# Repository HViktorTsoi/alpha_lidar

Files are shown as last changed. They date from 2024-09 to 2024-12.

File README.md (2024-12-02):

This is the official implementation of the paper **𝛼LiDAR: An Adaptive High-Resolution Panoramic LiDAR System (MobiCom 2024)**. 

# 𝛼LiDAR: An Adaptive High-Resolution Panoramic LiDAR System

The performance of current LiDAR sensors is hindered by limited field of view (FOV), low resolution, and lack of flexible focusing capability. We introduce 𝛼LiDAR, an innovative LiDAR system that employs controllable actuation to provide a panoramic FOV, high resolution, and adaptable scanning focus. See our demos below $\color{red}{\textbf{(3.7k+ views)}}$:

## Demo Video (YouTube)
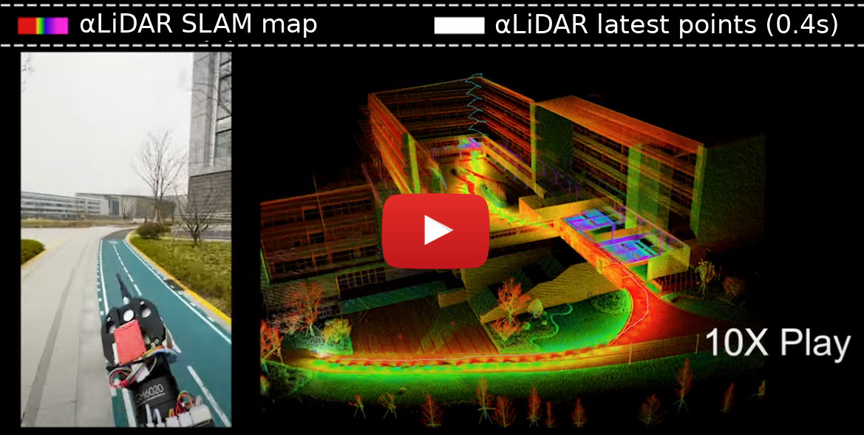
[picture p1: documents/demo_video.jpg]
alpha_lidar_demo_video (https://www.youtube.com/watch?v=x4zc_I_xTaw)


## System Overview 

The core concept of 𝛼LiDAR is to expand the operational freedom of a LiDAR sensor through the incorporation of a controllable, active rotational mechanism. This modification allows the sensor to scan previously inaccessible blind spots and focus on specific areas of interest in an adaptive manner. A major challenge with 𝛼LiDAR is that rapid rotations result in highly distorted point clouds. Our solution focuses on accurately estimating the LiDAR sensor’s pose during rapid rotations to effectively correct and reconstruct the point cloud.

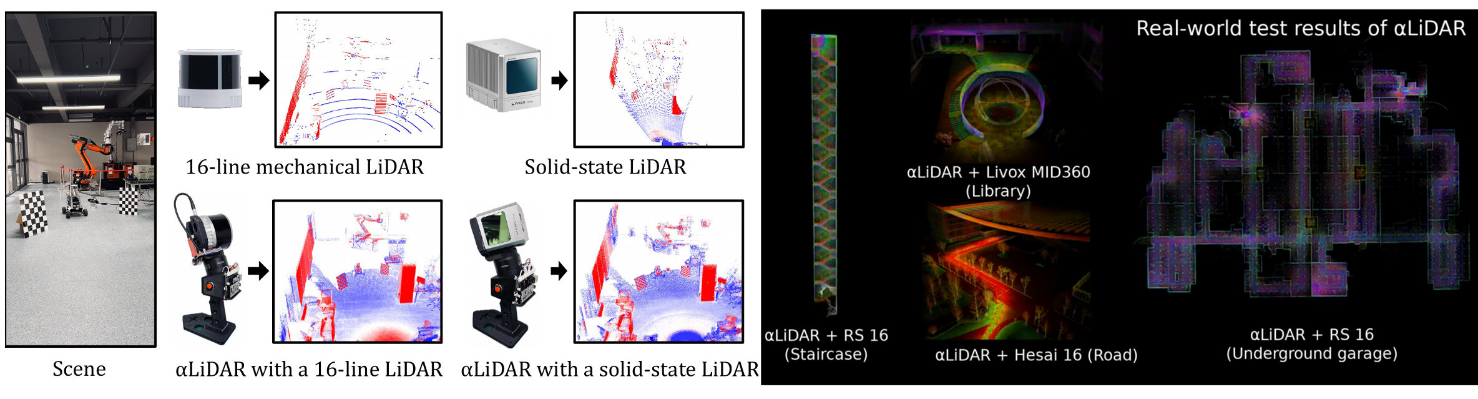
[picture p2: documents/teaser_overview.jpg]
Teaser)


# Table of Contents
This repository contains the hardware specifications, software, and datasets for reproducing and evaluating 𝛼LiDAR:

[//]: # (- [Demo video &#40;YouTube&#41;]&#40;#demo-video-youtube&#41;)
[//]: # (- [System Overview]&#40;#system-overview&#41;)
- [How to Use This Repo](#how-to-use-this-repo)
- [:gear: I. Hardware Guideline](#gear-i-hardware-guideline)
  - [1. Bill of Materials](#1-bill-of-materials)
  - [2. Build the Mechanical Components](#2-build-the-mechanical-components)
  - [3. Setup the Electronic Components](#3-setup-the-electronic-components)
- [:minidisc: II. Datasets](#minidisc-ii-prepare-code-and-datasets)
- [:scroll: III. Software Guideline](#scroll-iii-software-guideline)
  - [Run with Docker (Recommended)](#run-with-docker-recommended)
  - [Build Source from Scratch](#build-source-from-scratch)
- [License](#license)

# How to Use This Repo:

We offer two approaches for reproducing 𝛼LiDAR:

### Approach 1: Build the hardware from scratch, and then test 𝛼LiDAR's algorithm.

We provide a detailed hardware guideline, including design files and production parameters for mechanical and electronic parts, along with a step-by-step replication tutorial. 
Once the hardware is set up, users can collect datasets and test 𝛼LiDAR in real-time and on-site.
To begin, please refer to the [⚙️ I. Hardware guideline](#gear-i-hardware-guideline) and follow the instructions in the specified order.

### Approach 2: Directly test 𝛼LiDAR's core algorithm with pre-collected datasets.

We also provide pre-collected datasets with 𝛼LiDAR's. These datasets allow the users to directly test the performance of 𝛼LiDAR's core software components. 
For this approach, please directly refer to  [:minidisc: II. Prepare code and datasets](#minidisc-ii-prepare-code-and-datasets) and [# :scroll: III. Software guideline](#scroll-iii-software-guideline). 

# :gear: I. Hardware Guideline

𝛼LiDAR enhances its sensing ability by incorporating an activate rotation mechanism in the FoV-limited directions in the physical layer, therefore, implementing the complete hardware system is important. 
In this section, we will demonstrate the assembly of the hardware in detail, including the setup of sensors, mechanical structures and electronic components. 
We provide comprehensive Bill of Materials, 3D printing instructions, PCB designing and manufacturing details and firmware setup guides to ensure easy replication of 𝛼LiDAR. 
Following this guide, users can reproduce the full 𝛼LiDAR hardware system, as shown bellow, for data collection and performance validation.

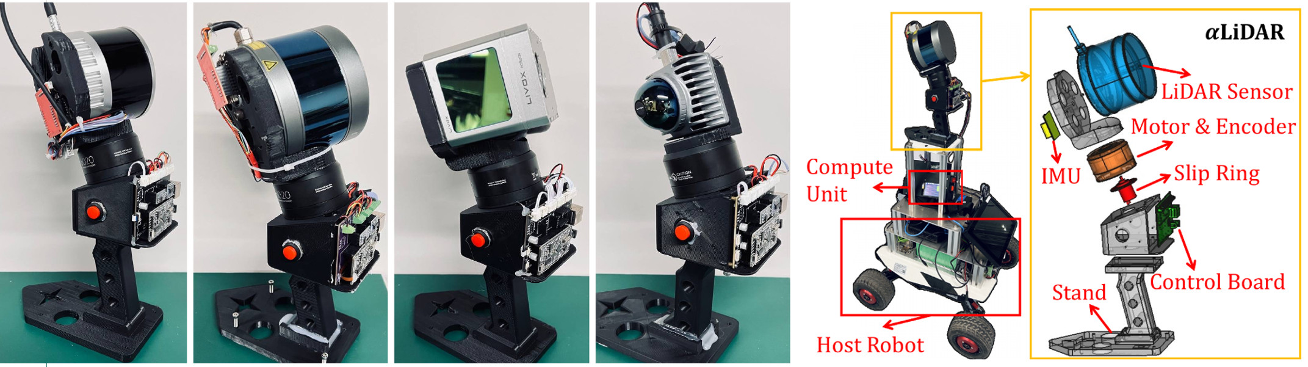
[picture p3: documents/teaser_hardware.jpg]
Teaser)


## 1. Bill of Materials

This section provides all materials required to replicate 𝛼LiDAR, including sensors, mechanical parts, electronic components, etc. 
Please prepare these materials before building 𝛼LiDAR.

Starting with sensors and actuators, 𝛼LiDAR requires a LiDAR with PPS/GPRMC time synchronization support (which is commonly built into most LiDARs).
𝛼LiDAR also requires an IMU and an encoder for state estimation, and a gimbal motor as the actuator for the active motion. The encoder is usually integrated into the gimbal motor such as DJI GM6020.
Specific models of these components are listed in the table below:

<details>
<summary>Click here to show the material list</summary>

| Component | Quantity | Detail | Link |
|---|---|---|---|
| Hesai Pandar XT-16 (*) | 1 | LiDAR with PPS+GPRMC sync support | [link](https://www.hesaitech.com/product_downloads/xt32-16/) |
| Yesense YIS100 | 1 | IMU | [link](https://www.yesense.com/YIS100) |
| Robomaster GM6020 | 1 | Motor / Encoder | [link](https://www.robomaster.com/en-US) |
> (*) Or other LiDAR sensors, e.g., [Robosense RS16](https://www.robosense.ai/en) / [Livox MID360](https://www.livoxtech.com/) / [Livox Horizon](https://www.livoxtech.com/).

</details>

Next, here are the mechanical and electronic parts required. Most of them can be purchased online with low cost. The purchase links are also provided if available.

<details>
<summary>Click here to show the material list</summary>

| Component | Quantity | Detail | Link |
|---|---|---|---|
| **Mechanical Parts** | | | |
| LanBo PLA+  filement | 1 | 3D printing filement | [link](http://e.tb.cn/h.gsp9zhNGv3aDk1e?tk=9Jja38xDsqf) |
| Central mounting structure | 1 | 3D printed part | [.step](hardware/Mechanical/center_mounting_structure_hesai.step)  |
| Motor mounting base | 1 | 3D printed part | [.step](hardware/Mechanical/motor_mounting_base.step) |
| Stand | 1 | 3D printed part | [.step](hardware/Mechanical/stand.step) |
| Hex socket cap screws | 18 | 7 x M3 x 10mm, 7 x M4 x 10mm, 4 x M4 x 25mm | - |
| W1/4-20 screws | 1 | - | - |
| **Electronic Parts** | | | |
| Control board | 1 | PCB | [link](hardware/PCB/EasyEDA_PCB_control_board.json) |
| Host machine interface | 1 | PCB | [link](hardware/PCB/EasyEDA_PCB_host_machine_interface.json) |
| STM32F103C8 Dev Board | 1 | MCU | [link](http://e.tb.cn/h.grrLx6RYA14IKhd?tk=78g03iXNOQm) |
| SP3232 Module | 1 | RS232-TTL converter | [link](http://e.tb.cn/h.gJosLscFDzw8Mb8?tk=u5v037C8lvo) |
| TJA1050 CAN Module | 1 | CAN controller | [link](http://e.tb.cn/h.gJRE7eLncdnfH2f?tk=bT1N37CR3JV) |
| CH340C SOP16 | 1 | USB-Serial converter | [link](http://e.tb.cn/h.gJLbUM7WQJP9YyL?tk=Q6bh37CsSeL) |
| SL2.1A SOP16 | 1 | USB hub controller | [link](http://e.tb.cn/h.gJ8WnEJFgmtsBG9?tk=nUKr37Cryhm) |
| 0805 chip beads | 1 | EMI protection | [link](http://e.tb.cn/h.gHOAsfEj4iIVgE7?tk=P8kt38CdGI0) |
| RJ45 Socket | 3 | Control board x1, interface board x2 | [link](http://e.tb.cn/h.gJRwBsI2jhjfMgq?tk=Blwl37Cjqox) |
| XH2.54 Socket | 5 | 8pin x1, 4pin x2, 2pin x2 | [link](http://e.tb.cn/h.gJRx9rqzKRJdwGG?tk=2ZND37CQ6tV) |
| Gigabit Ethernet cable | 1 | 8-line, for data transmission | - |

</details>

## 2. Build the Mechanical Components

𝛼LiDAR's mechanical components including the structural parts for mounting the LiDAR, IMU, Motor, and the control board. 
Our design is optimized for 3D printing to facilitate rapid prototyping and reproducing. 

### 2.1 Prepare the CAD Models:
First, download the following CAD models of the mechanical components. 
The user can preview the assembly diagram and the part files with [FreeCAD](https://www.freecad.org/) software and [A2plus plugin](https://wiki.freecad.org/A2plus_Workbench).

<details>
<summary>Click here to show the CAD files: </summary>

- Assembly diagram: 

[hardware/Mechanical/assembly.FCStd](hardware/Mechanical/assembly.FCStd)

- LiDAR-IMU-Motor central mounting structure (for Hesai Pandar XT16)

[hardware/Mechanical/center_mounting_structure_hesai.step](hardware/Mechanical/center_mounting_structure_hesai.step)

- LiDAR-IMU-Motor central mounting structure (for Robosense RS16)

[hardware/Mechanical/center_mounting_structure_rs16.step](hardware/Mechanical/center_mounting_structure_rs16.step)

- Motor mounting base

[hardware/Mechanical/motor_mounting_base.step](hardware/Mechanical/motor_mounting_base.step)

- Stand

[hardware/Mechanical/stand.step](hardware/Mechanical/stand.step)

</details>

### 2.2 Build the Components with a 3D Printer

The users can then import the above STEP files into a 3D printing slicing software, set the printing parameters to generate the `.gcode` files, and then use a 3D printer to build the parts.
For reference, we use a **SnapMaker A350 3D printer**, and use **Ultimaker Cura 4.9.1** for model slicing.

<details>
<summary>Click here to show the key parameters for 3D printing: </summary>

- **Printing material:** Lanbo PLA+
- **Temperature:** 200C
- **Heat bed:** 60C
- **Cooling fan:** 100%
- **Nozzle diameter:** 0.4mm
- **Layer height:** 0.24mm
- **Wall line count:** 4
- **Top-bottom layers:** 4
- **Infill:** 60% Gyroid
- **Support:** On
- **Adhesion:** On 
- **Build plate adhesion type:** Brim

</details>

To ensure that the printed parts have sufficient layer strength during rapid rotations, we require specific placement for the models in the slicing software.
The orientation of the sliced models should be positioned like this:

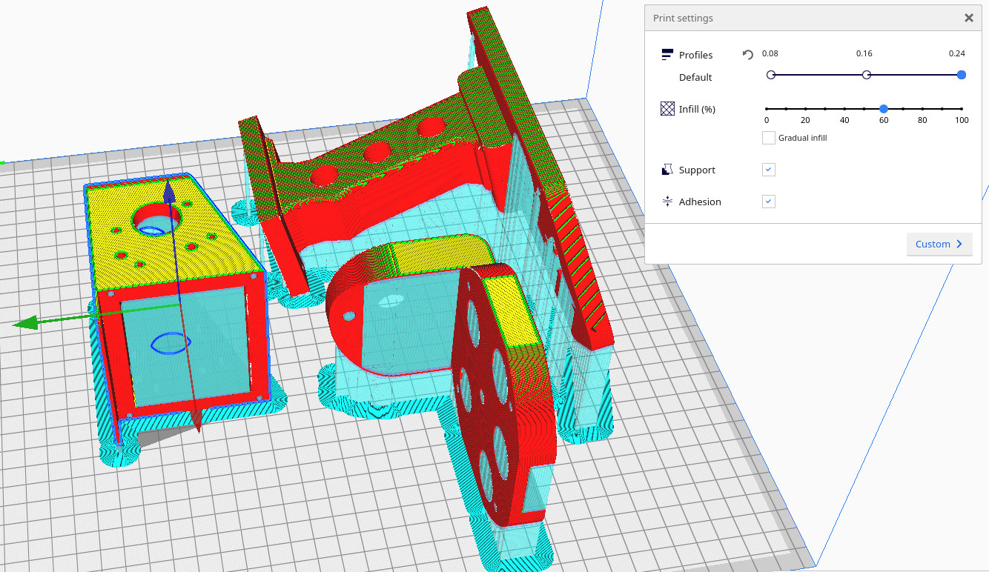
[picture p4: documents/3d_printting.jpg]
3D Printing Preview


## 3. Setup the Electronic Components

𝛼LiDAR's electronic components mainly consists of two PCBs:  the **control board** and the **host machine interface**.

The **control board** is mounted together with the Motor, LiDAR, IMU sensor, aggregating all sensor data onto a single RJ45 physical interface, and transmitting the data via a 8-line gigabit Ethernet cable; 

the **host machine interface** splits the 8-line gigabit Ethernet cable into a 4-line 100Mbps Ethernet and a USB 2.0 interface, connecting to the host computer.

### 3.1 Preview the PCB Designing Files

<details>
<summary>Click here to show the PCB design files: </summary>

- Control board PCB design file:

[hardware/PCB/EasyEDA_PCB_control_board.json](hardware/PCB/EasyEDA_PCB_control_board.json)

- Host machine interface PCB design file:

[hardware/PCB/EasyEDA_PCB_host_machine_interface.json](hardware/PCB/EasyEDA_PCB_host_machine_interface.json)

</details>

The PCB design files can be imported and previewed in [EasyEDA](https://easyeda.com/editor). After successful importation, the appearance of the PCB should look as shown in the following images:

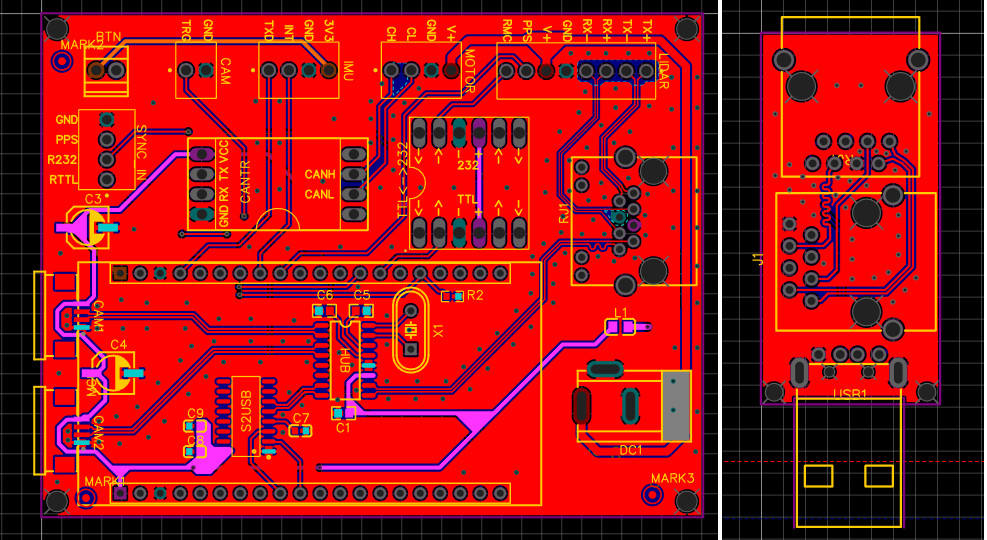
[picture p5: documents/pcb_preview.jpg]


### 3.2 Manufacture the PCBs

The PCBs can be manufactured using [JLCPCB's PCB Prototype service](https://docs.lceda.cn/en/PCB/Order-PCB/), which has been integrated within EasyEDA.

<details>
<summary>Click here to show the key parameters for PCB fabrication: </summary>

- **Base Material:** FR-4
- **Layers:** 2
- **Product Type:** Industrial/Consumer electronics
- **PCB Thickness:** 1.6
- **Surface Finish:** HASL(with lead)
- **Outer Copper Weight:** 1oz
- **Min via hole size/diameter:** 0.3mm
- **Board Outline Tolerance:** +-0.2mm

</details>

To assemble the MCU and other electronic components onto the PCB, we can use [JLCPCB's SMT service](https://jlcpcb.com/smt-assembly), or solder by hand. The fully assembled PCB is shown in the following images:

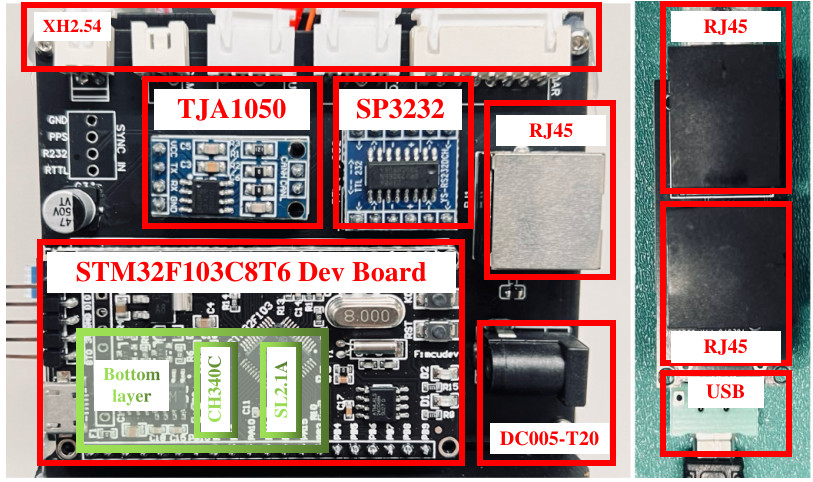
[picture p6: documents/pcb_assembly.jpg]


### 3.3 Uploading the Firmware

The firmware needs to be programmed into the STM32 MCU on the control board. It includes all the functionalities necessary for the board to operate properly, including data acquisition from multiple sensors, time synchronization,  protocol conversion, etc. 

The hex file of the firmware:
[hardware/Firmware/stm32f103c8t6.hex](hardware/Firmware/stm32f103c8t6.hex)

To program the firmware onto the MCU, we need an [ST-LINK V2](https://www.st.com/en/development-tools/st-link-v2.html) programmer. Please refer to the programming process outlined in the[STM32CubeProgrammer user manual](https://www.st.com/resource/en/user_manual/um2237-stm32cubeprogrammer-software-description-stmicroelectronics.pdf).

### 3.4 Wire Everything Together

After preparing all the required sensors, actuators, and the assembled PCB, please connect the components according to the wiring diagram below. 
The diagram includes the PIN definitions for each sensor's XH2.54 interface, arranged in the same order as they appear on the actual PCB. 
The entire PCB (and the sensors) can be powered through a DC 24V input.

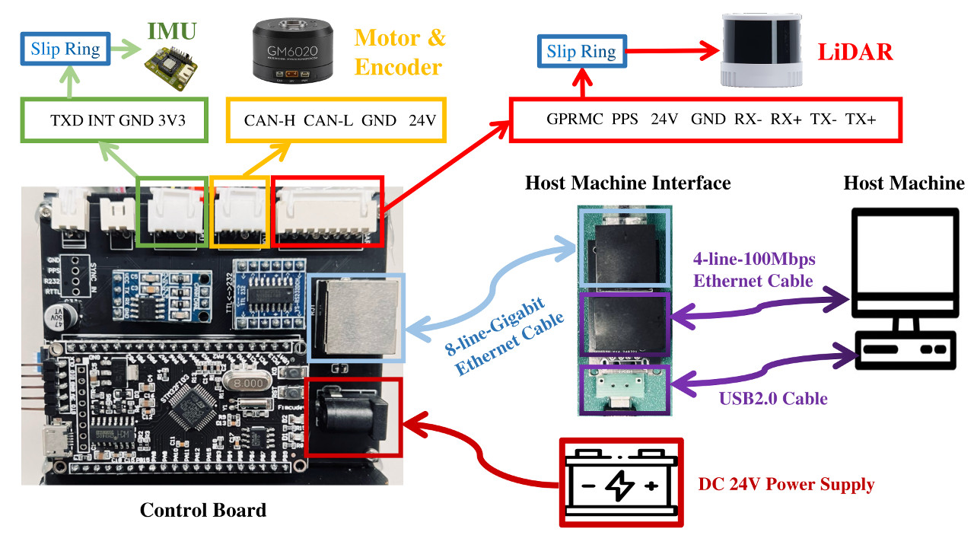
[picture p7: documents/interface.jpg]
Wire


# :minidisc: II. Prepare Code and Datasets

We also provide multiple pre-collected datasets to test 𝛼LiDAR's performance if the hardware is not available. The dataset can be downloaded at [Mega Drive](https://mega.nz/folder/fEpwARjD#AVRIQ-gzrFtTJn6fuwmXng) or [Baidu Pan (Code: u0tr)](https://pan.baidu.com/s/1nzBAgfkNCF8X1rAMBUw8Rg).

**Dataset description:**

| Test dataset | Description | Scene image and map |
|---|---|:---:|
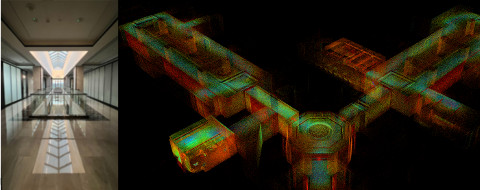
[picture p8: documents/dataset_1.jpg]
data
| alpha_lidar_large_indoor.bag | Indoor environment with narrow corridors and reflective floors |  |
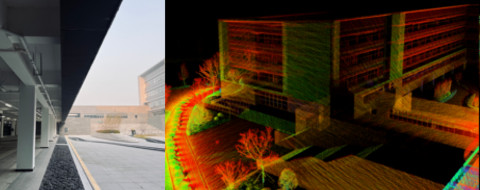
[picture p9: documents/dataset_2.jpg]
data
| alpha_lidar_various_scene.bag | Hybrid indoor and outdoor environment |  |
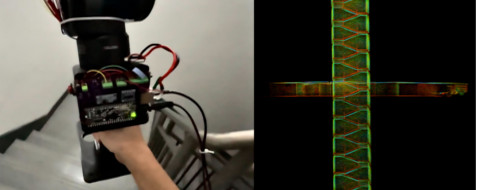
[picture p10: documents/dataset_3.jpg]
data
| alpha_lidar_15floors_staircase.bag | 15-Floor narrow stairwell |  |

To use our code and datasets, first, clone this repository:
```shell
git clone https://github.com/HViktorTsoi/alpha_lidar.git
```

Download the datasets and save to this path: 
```shell
${path_to_alpha_lidar}/datasets
```
`${path_to_alpha_lidar}` is the path to the source code just been cloned. 

After downloading, the `alpha_lidar/datasets` directory should look like this:

```shell
|-- datasets
|---- alpha_lidar_15floors_staircase.bag
|---- alpha_lidar_large_indoor.bag
|---- alpha_lidar_large_indoor.fusion.gt
|---- alpha_lidar_various_scene.bag
|---- alpha_lidar_various_scene.f9p.gt
```
The `*.bag` files store the raw data (LiDAR point cloud, IMU and Encode messages), while the corresponding `*.gt` files store the ground truth data.

# :scroll: III. Software Guideline

> A step-by-step video tutorial for this section is available at https://www.youtube.com/watch?v=jFgedPY6zIM

In this section, we demonstrate how to run and evaluate 𝛼LiDAR's core software module, which addresses 𝛼LiDAR' main challenges: accurately estimating the LiDAR's poses and recovering undistorted LiDAR measurements under the rapid motion of both the LiDAR and the carrier.

We offer two methods for running the 𝛼LiDAR code: 
[running with docker (we recommend)](#run-with-docker-recommended) and [building the source code from scratch](#build-source-from-scratch).

## Run with Docker (Recommended)

### Prerequisites

- Ubuntu 18.04 or later
- NVIDIA GPU Driver
- [docker](https://docs.docker.com/get-docker/)
- [nvidia-docker2](https://docs.nvidia.com/datacenter/cloud-native/container-toolkit/install-guide.html)
- [docker-compose](https://docs.docker.com/compose/install/linux/#install-using-the-repository)

### 1. Setup Docker Environment
First, pull our preconfigured environment from docker hub
```shell
docker pull hviktortsoi/ubuntu2004_cuda_ros:latest
```
Then, enter the `docker` directory in the source code

```shell
cd ${path_to_alpha_lidar}/software/docker
```
`${path_to_alpha_lidar}` is the path where the source code just been cloned. 

Before start the container, configure `xhost` on the host machine by:
```shell
sudo xhost +si:localuser:root
```

Then launch and enter the docker container:
```shell
sudo docker-compose run alpha-lidar bash
```

### 2. Run and Evaluate

The following steps are all executed in the bash terminal inside the docker container. 
#### 2.1 Run αLiDAR

Taking the `alpha_lidar_various_scene.bag` dataset as an example, to launch αLiDAR's `state estimation` module, execute:

```shell
roslaunch state_estimation mapping_robosense.launch bag_path:=/datasets/alpha_lidar_large_indoor.bag
```
After launching, press `space` key in the **bash terminal** to begin data playback.

If everything is working smoothly, two RVIZ GUI windows will show up:

The first RVIZ window shows the visualization of αLiDAR's **point cloud maps** and **estimated poses**. 
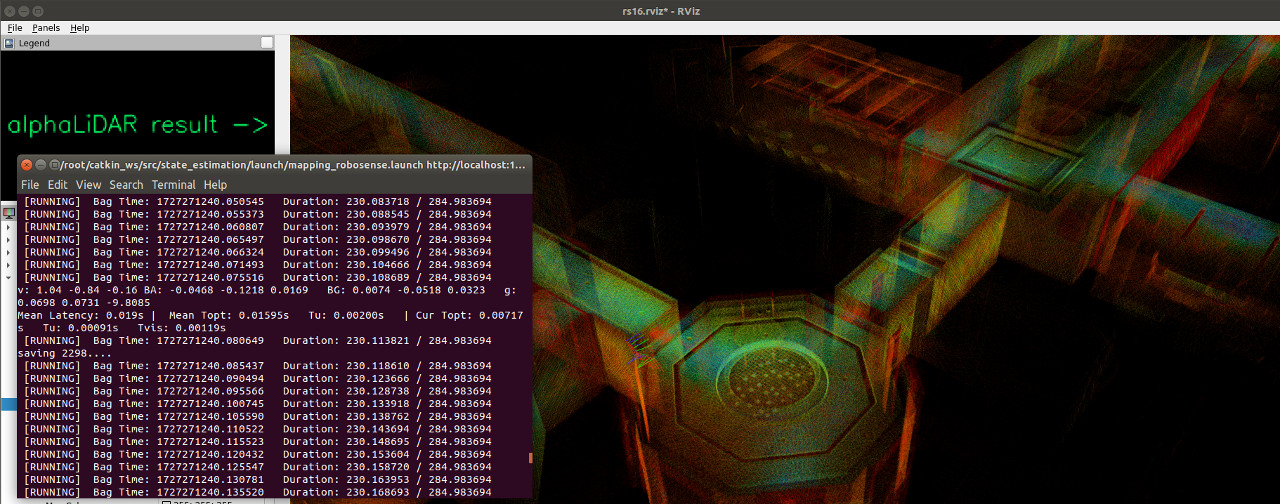
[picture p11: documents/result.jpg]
result


The smaller second window shows the comparison result, which is naïvely stacking the raw point clouds without αLiDAR's pipeline.

[//]: # (![result]&#40;documents/result3.jpg&#41;)
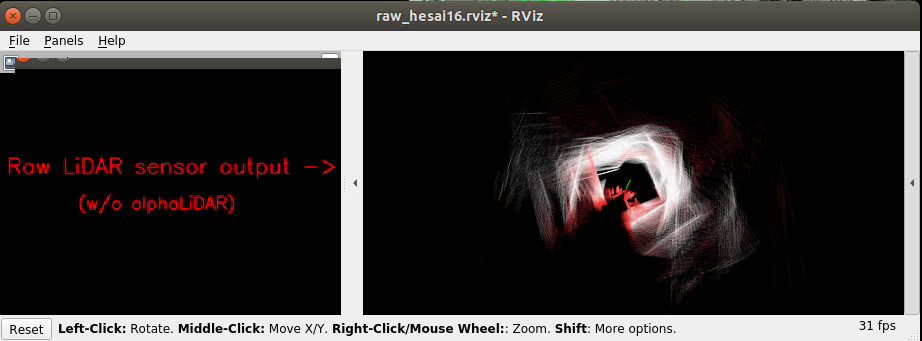
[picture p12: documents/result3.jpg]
result


Additionally, the bash terminal will display the debug information like data playback time, real-time latency, etc.

Users can use the mouse **Left-click**, **Middle-scroll** and **Middle-click** to move the viewpoint in the RVIZ GUI to observe a more comprehensive point cloud map. 

During visualization, if the users lost the point cloud view, press `z` key in the RVIZ GUI to reset the viewpoint;
If the point clouds are not clear, try increasing the `Size (m)` parameter (e.g., to 0.05) in the left configuration panel to make the point cloud more visible.

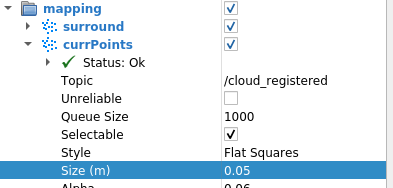
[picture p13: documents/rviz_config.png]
config


#### 2.2 Evaluate αLiDAR's Performance
After completing data playback, press CTRL+C in the  **bash terminal** to exit `state estimation`.

To evaluate αLiDAR's performance，execute：
```shell
rosrun state_estimation evaluation.py --gt_path /datasets/alpha_lidar_large_indoor.fusion.gt
```
It shows the evaluation results of trajectory precision, latency, FoV coverage, etc.

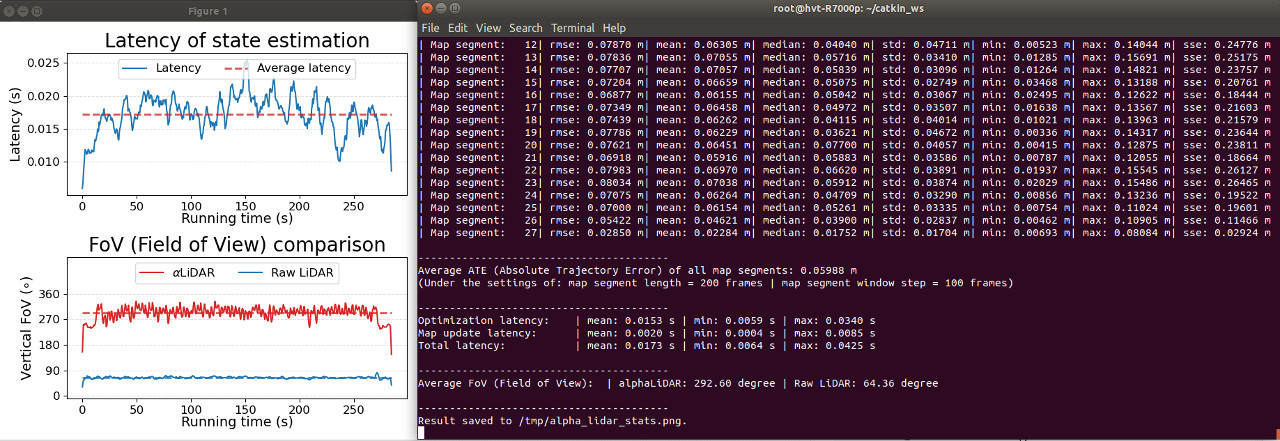
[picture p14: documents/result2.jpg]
result


#### 2.3 Other Datasets
For `alpha_lidar_15floors_staircase.bag` dataset, execute the following commands to run and evaluate:
```shell
# run
roslaunch state_estimation mapping_robosense.launch bag_path:=/datasets/alpha_lidar_15floors_staircase.bag
# evaluate
rosrun state_estimation evaluation.py 
```

For `alpha_lidar_various_scene.bag` dataset, execute the following commands to run and evaluate, note that a different `.launch` file is used here:
```shell
# run
roslaunch state_estimation mapping_hesai.launch bag_path:=/datasets/alpha_lidar_various_scene.bag
# evaluate
rosrun state_estimation evaluation.py --gt_path /datasets/alpha_lidar_various_scene.f9p.gt
```
[//]: # (![Teaser&#41;]&#40;documents/teaser_slam.jpg&#41;)

## Build Source from Scratch

### Prerequisites
#### System-level requirements:
- **Ubuntu 18.04 or later.**
- **ROS melodic or later.** Follow [ROS Installation](http://wiki.ros.org/ROS/Installation).
- **PCL 1.8 or later.** Follow [PCL Installation](http://www.pointclouds.org/downloads/linux.html).
- **Eigen 3.3.4 or later.** Follow [Eigen Installation](http://eigen.tuxfamily.org/index.php?title=Main_Page).
- **livox_ros_driver1.** Follow [livox_ros_driver Installation](https://github.com/Livox-SDK/livox_ros_driver).
> *Remarks:* The **livox_ros_driver** must be installed and **sourced** before run any 𝛼LiDAR's state_estimation launch file.

> *Remarks:* How to source? The easiest way is add the line ``` source $Livox_ros_driver_dir$/devel/setup.bash ``` to the end of file ``` ~/.bashrc ```, where ``` $Livox_ros_driver_dir$ ``` is the directory of the livox ros driver workspace (should be the ``` ws_livox ``` directory if you completely followed the livox official document).

#### Python requirements:
- Python 3.7 or later
- [evo](https://github.com/MichaelGrupp/evo)
- opencv-python
- ros_numpy
- transforms3d

### 1. Build
Enter the catkin workspace directory:
```shell
cd ${path_to_alpha_lidar}/software/alpha_lidar_ws
```

`${path_to_alpha_lidar}` is the path where the source code just been cloned. 

Then compile the code

```shell
catkin_make -DCATKIN_WHITELIST_PACKAGES="state_estimation"
```

and source

```shell
source ./devel/setup.bash
```

### 2. Run and Evaluate
This process follows the same steps as outlined in the [Run with Docker (Recommended)](#run-with-docker-recommended), 
please refer to this section [2. Run and Evaluate](#2-run-and-evaluate) for detailed instructions.

# License
This repository is released under the MIT license. See [LICENSE](LICENSE) for additional details.

# Acknowledgement

Thanks [@Jinwen](https://github.com/zhujinwen0924) for teaching me how to design PCBs; Thanks [@Yuchen](https://github.com) for helping me build the prototypes.

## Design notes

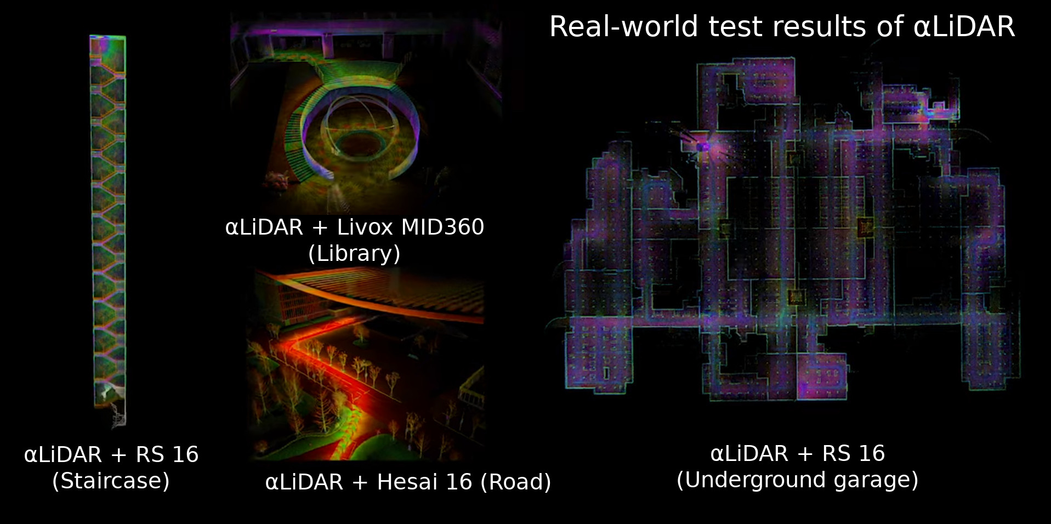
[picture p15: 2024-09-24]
documents/teaser_slam.jpg

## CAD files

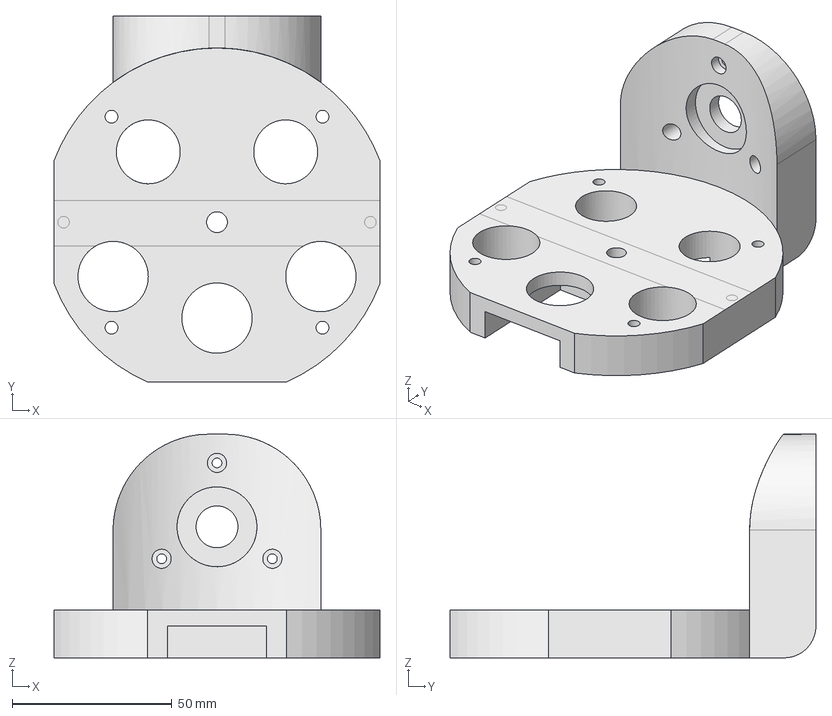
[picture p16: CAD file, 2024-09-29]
hardware/Mechanical/center_mounting_structure_hesai.step
102.0 x 114.5 x 70.0 mm

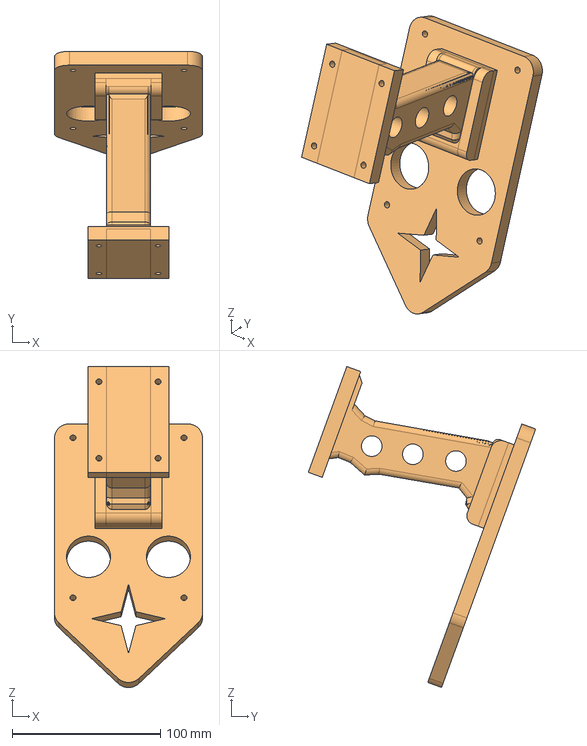
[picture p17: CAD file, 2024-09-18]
hardware/Mechanical/stand.step
100.0 x 153.6 x 216.8 mm

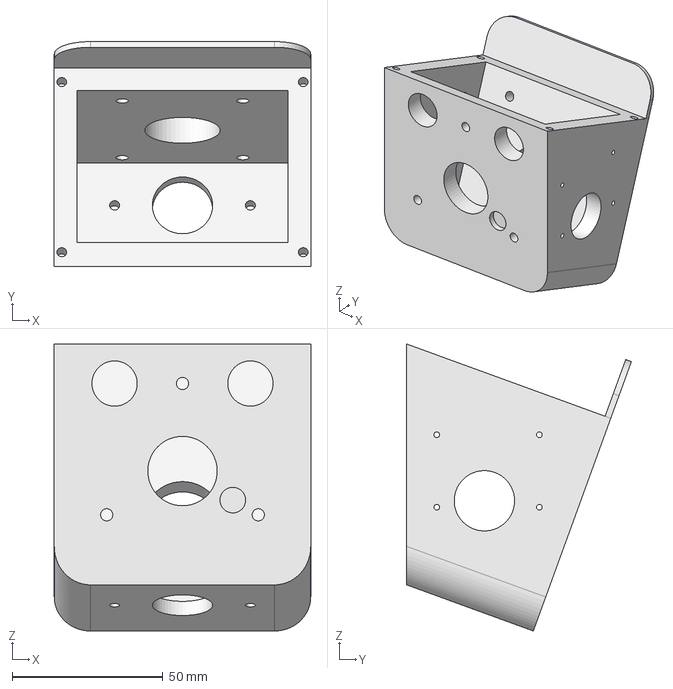
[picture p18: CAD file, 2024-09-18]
hardware/Mechanical/motor_mounting_base.step
85.0 x 74.5 x 95.1 mm

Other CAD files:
hardware/Mechanical/center_mounting_structure_ra16.step

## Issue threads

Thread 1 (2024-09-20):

test dataset

chengwei0427, 2024-09-20:
Hi, @HViktorTsoi

Great work! Are there any publicly available datasets for SLAM testing?

HViktorTsoi, 2024-09-20:
Yes！We are uploading the datasets in the next few days

chengwei0427, 2024-09-24:
Thanks for your work, and looking forward to the dataset being open-sourced.

chengwei0427, 2024-09-29:
Hi, @HViktorTsoi @yuzehh
I downloaded the data you shared in your alpha_lidar repository. However, since the LiDAR keeps rotating from the moment the bag is opened, I have tested FastLIO2, Point-LIO, and IG-LIO, but none of them are running correctly. Could you please advise on how to make this data work? Is dynamic initialization necessary to get it running?

HViktorTsoi, 2024-09-29:
Hi, the datasets may be challenging for other LIOs to initialize due to rapid rotation from the begining. αLiDAR has a  non-static initialization strategy when starting state estimation. Please test with our uploaded code and see the initialization part.

Also please check if the [initial LiDAR-IMU extrinsics](https://github.com/HViktorTsoi/alpha_lidar/blob/a336d02454decaba03336e24fa650bfa089e1f69/software/alpha_lidar_ws/src/state_estimation/config/rs16_rotation_v2.yaml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) are correct.

satyajitghana, 2024-10-03:
@chengwei0427 i think you'll also need to fuse encoder data as well to state estimation in other slam algorithms

https://github.com/HViktorTsoi/alpha_lidar/blob/4f7c6ef2f747e8992846cadd01952fbbaaa8ce0f/software/alpha_lidar_ws/src/state_estimation/src/voxelMapping.cpp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

Closed 2024-11-26.

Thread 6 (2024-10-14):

Host Machine & Livox IMU info

satyajit-ink, 2024-10-14:
what is the details of the host machine used with alpha lidar?

also is the external IMU necessary in case of Livox Lidar's with inbuilt IMU?

HViktorTsoi, 2024-10-14:
Hi, you could use a normal laptop (with Ethernet and USB interface) as the host machine. For reference, we're using a Lenovo LEGION R7000P laptop with NVIDIA 2060GPU and 16-core CPUs.

For Livox LiDARs, the external IMU is not required, you could use the built-in 6-axis IMU. However, if the test scenario requires dynamic initialization, you may need [imu_filter_madgwick](https://wiki.ros.org/imu_filter_madgwick) to generate the initial imu orientation.

Closed 2024-10-14.

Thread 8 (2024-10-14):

Livox MID360 Dataset

satyajit-ink, 2024-10-14:
Hi, i couldn't find the MID360 dataset bag files, but it was tested in the demo video.

himhan34, 2024-12-08:
also eager to  see the  mid-360 sensor mount! have a great day and
i heard that you guys got the prise  in the conference  congrets!

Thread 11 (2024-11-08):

how to setup MID-360 lidar

NamDinhRobotics, 2024-11-08:
Thanks for your great work,
I want to ask how to connect the board with mid-360, do you have a schematic for the connection?

Bests,

85256638, 2024-11-25:
I acutally raised the same question regarding the connecting base for Livox Horizon and Mid-360. Would be great to have the CAD files for those Lidars.

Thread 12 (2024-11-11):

Any difference between PV-LIO and the software code of alpha-lidar

CharlieV5, 2024-11-11:
Hi!
I have followed you works of PV-LIO and noticed that the software code of alpha-lidar seems to be almost using the same code of PV-LIO. So what is the crucial difference between PV-LIO and alpha-lidar software code ?

HViktorTsoi, 2024-11-26:
Hi! PV-LIO is an under-developing version of αLiDAR. There are two main updates of this repo compared with PV-LIO  :
1. Non-static initialization for rapid rotation scenarios.
2. Uncoupled motor encoder fusion.

Closed 2024-11-29.

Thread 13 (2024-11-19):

Regarding the source of the topic /imu/encoder

Luthermorning, 2024-11-19:
Thank you for your open source work for contributing to the community, I would like to know how your encoder data is emitted from STM32 and received in ROS, can you discuss this with you.

HViktorTsoi, 2024-11-26:
Hi,  the data link path of the encoder message is like this:

Motor --> [Encoder angle packets] --> CAN --> stm32 --> [Timestamping and packing the angle packets together with adjecent IMU packets] --> USART --> Host machine --> ROS serial driver --> [Decode both IMU and angle packets and publish them as /imu/data and /imu/encoder]

Luthermorning, 2024-11-27:
> Hi, the data link path of the encoder message is like this:
>
> Motor --> [Encoder angle packets] --> CAN --> stm32 --> [Timestamping and packing the angle packets together with adjecent IMU packets] --> USART --> Host machine --> ROS serial driver --> [Decode both IMU and angle packets and publish them as `/imu/data` and `/imu/encoder`]

Thanks, it`s cool.

Closed 2024-11-29.

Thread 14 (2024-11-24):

LiDAR-lMU-Motor central mounting structure for Livox Lidars.

85256638, 2024-11-24:
Thanks a lot for open-sourcing this great project.

Would be able to provide the CAD design files for other Lidars please? Especially the Livox Horizon and Livox Mid-360.
The current repository only contains designs for two Lidars:

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

HViktorTsoi, 2024-11-26:
#11

HViktorTsoi, 2024-11-26:
#8

Closed 2024-12-03.

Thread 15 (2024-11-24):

Slip Ring and 24V Battery

85256638, 2024-11-24:
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

Hi, could you kindly provide details about the slip ring and the 24V battery you used in this project?
Thanks!

HViktorTsoi, 2024-11-26:
Hi, we use a Senring slip ring (12 line).  The 24V battery can be any off-the-shelf Lithum-ion battery with at least 1A current support, e.g., this one [Taobao Link](https://item.taobao.com/item.htm?id=660918833068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). We actually mount the battery together with the host machine and connect it through a extended power cable. But you can also mount that inside the base like the picture above.

85256638, 2024-11-29:
Thanks a lot for providing details about the slip ring.

I contacted Senring, but their pre-sales person couldn't not identify the exact model number from the CAD file, and the photos from this project page. Therefore, could you kindly provide the detailed part number of the slip ring used? This would help massively! 👍

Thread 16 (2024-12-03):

A summary of the missing information required to re-produce this work

85256638, 2024-12-03:
Thanks a lot for your dedication to open-source this great piece of work. After thoroughly review the readme, I summarised a list of missing information which required to re-produce this work:

1. Exact model number of the sliping  #15
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
_Senring sales team were unable to work out the model used._

2. BOM of the PCB board.
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
 _i.e. the capacitor, crystal oscalliator used in this project etc._

3. Mounting structures for Livox Lidars. #14

5. Information about the red IMU board used for Hesai and Velodyne Lidar
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

6. STM32 source code #9

8.  what is the purpose of this little red button?
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

himhan34, 2024-12-23:
@85256638 maybe i wish this helps you
i  think the slip ring that the author used is  the pic which is in below, especially the  size is 22mm, 12ch, 5A
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

himhan34, 2024-12-23:
me either are looking for the right control panel bom!
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

jxx315, 2024-12-24:
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

The hollow shaft of this motor has an inner diameter of 18mm,    Slip Rings with 22mm OD cannot be adapted.

jxx315, 2024-12-24:
> me either are looking for the right control panel bom! ![image](https://private-user-images.githubusercontent.com/46841767/398168693-eeb0f0f7-0bdf-4438-90a3-41f5c60757b3.png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)

Slip Rings with 22mm OD cannot be adapted.

himhan34, 2024-12-24:
> > me either are looking for the right control panel bom! ![image](https://private-user-images.githubusercontent.com/46841767/398168693-eeb0f0f7-0bdf-4438-90a3-41f5c60757b3.png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)
>
> Slip Rings with 22mm OD cannot be adapted.

as i understood outer diameter is 22mm

jxx315, 2024-12-25:
> as i understood outer diameter is 22mm

The inner diameter of the motor is 18mm, the outer diameter is 22mm, the outer diameter of the slip ring is 22mm, how to insert it?

himhan34, 2024-12-25:
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

as you can see in here I think we can insert the slip ring cuz the od of the platform is 22mm

himhan34, 2024-12-25:
i think i had given the wrong information so I erased all, after checking the right information I will comment.

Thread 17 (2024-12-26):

Collect your own bag files

sczgzzzj, 2024-12-26:
Very good results, I would like to ask if the hardware assembly is completed, how to collect their own bag data , what operations are needed?

satyajit-ink, 2024-12-31:
i think the data collection code is not shared

himhan34, 2025-01-03:
@sczgzzzj
I’m curious about something.
It seems like the slip ring and PCB might not be compatible. How did you resolve this issue?

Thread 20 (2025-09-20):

Where to buy the Yesense YIS100?

Pretzandalf, 2025-09-20:
Hello,
Could you please advise where else I can buy the YIS100. In the README under the Bill of Materials section, there is a link to the official Yesense website for purchasing. However, when I follow the purchase link on their website, it leads to an error page (item not found).

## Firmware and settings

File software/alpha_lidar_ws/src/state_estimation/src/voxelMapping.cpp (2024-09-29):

// This is an advanced implementation of the algorithm described in the
// following paper:
//   J. Zhang and S. Singh. LOAM: Lidar Odometry and Mapping in Real-time.
//     Robotics: Science and Systems Conference (RSS). Berkeley, CA, July 2014.

// Modifier: Livox               dev@livoxtech.com

// Copyright 2013, Ji Zhang, Carnegie Mellon University
// Further contributions copyright (c) 2016, Southwest Research Institute
// All rights reserved.
//
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
// THIS SOFTWARE IS PROVIDED BY THE COPYRIGHT HOLDERS AND CONTRIBUTORS "AS IS"
// AND ANY EXPRESS OR IMPLIED WARRANTIES, INCLUDING, BUT NOT LIMITED TO, THE
// IMPLIED WARRANTIES OF MERCHANTABILITY AND FITNESS FOR A PARTICULAR PURPOSE
// ARE DISCLAIMED. IN NO EVENT SHALL THE COPYRIGHT HOLDER OR CONTRIBUTORS BE
// LIABLE FOR ANY DIRECT, INDIRECT, INCIDENTAL, SPECIAL, EXEMPLARY, OR
// CONSEQUENTIAL DAMAGES (INCLUDING, BUT NOT LIMITED TO, PROCUREMENT OF
// SUBSTITUTE GOODS OR SERVICES; LOSS OF USE, DATA, OR PROFITS; OR BUSINESS
// INTERRUPTION) HOWEVER CAUSED AND ON ANY THEORY OF LIABILITY, WHETHER IN
// CONTRACT, STRICT LIABILITY, OR TORT (INCLUDING NEGLIGENCE OR OTHERWISE)
// ARISING IN ANY WAY OUT OF THE USE OF THIS SOFTWARE, EVEN IF ADVISED OF THE
// POSSIBILITY OF SUCH DAMAGE.
#include <omp.h>
#include <mutex>
#include <math.h>
#include <thread>
#include <fstream>
#include <csignal>
#include <unistd.h>
#include <Python.h>
#include <so3_math.h>
#include <ros/ros.h>
#include <Eigen/Core>
#include "IMU_Processing.hpp"
#include <nav_msgs/Odometry.h>
#include <nav_msgs/Path.h>
#include <pcl_conversions/pcl_conversions.h>
#include <pcl/point_cloud.h>
#include <pcl/filters/voxel_grid.h>
#include <pcl/filters/random_sample.h>
#include <sensor_msgs/PointCloud2.h>
#include <std_msgs/String.h>
#include <tf/transform_datatypes.h>
#include <tf/transform_broadcaster.h>
#include <geometry_msgs/Vector3.h>
#include <livox_ros_driver/CustomMsg.h>
#include "preprocess.h"
#include "voxel_map_util.hpp"

#include <rosbag/bag.h>
#include <rosbag/view.h>
#include <boost/foreach.hpp>
#define foreach BOOST_FOREACH

#define INIT_TIME           (0.1)
#define LASER_POINT_COV     (0.001)
#define MAXN                (720000)
#define PUBFRAME_PERIOD     (20)

/*** Time Log Variables ***/
double kdtree_incremental_time = 0.0, kdtree_search_time = 0.0, kdtree_delete_time = 0.0;
double T1[MAXN], s_plot[MAXN], s_plot2[MAXN], s_plot3[MAXN], s_plot4[MAXN], s_plot5[MAXN], s_plot6[MAXN], s_plot7[MAXN], s_plot8[MAXN], s_plot9[MAXN], s_plot10[MAXN], s_plot11[MAXN];
double match_time = 0, solve_time = 0, solve_const_H_time = 0;
int    kdtree_size_st = 0, kdtree_size_end = 0, add_point_size = 0, kdtree_delete_counter = 0;
bool   time_sync_en = false, extrinsic_est_en = true, path_en = true, encoder_fusion_en=true;
double lidar_time_offset = 0.0;
double encoder_zeropoint_offset_deg = 0.0;
/**************************/

float res_last[100000] = {0.0};
float DET_RANGE = 300.0f;
const float MOV_THRESHOLD = 1.5f;
double intensity_th = 1.0f;

mutex mtx_buffer;
condition_variable sig_buffer;

string root_dir = ROOT_DIR;
string  lid_topic, imu_topic, encoder_topic;

double res_mean_last = 0.05, total_residual = 0.0;
double last_timestamp_lidar = 0, last_timestamp_imu = -1.0;
double gyr_cov = 0.1, acc_cov = 0.1, b_gyr_cov = 0.0001, b_acc_cov = 0.0001;
double filter_size_surf_min = 0;
double total_distance = 0, lidar_end_time = 0, first_lidar_time = 0.0, lidar_end_time_prev=0;
int    effct_feat_num = 0, time_log_counter = 0, scan_count = 0, publish_count = 0;
int    iterCount = 0, feats_down_size = 0, NUM_MAX_ITERATIONS = 0, laserCloudValidNum = 0, pcd_index = 0;
int scan_index = 0;
bool   point_selected_surf[100000] = {0};
bool   lidar_pushed, flg_first_scan = true, flg_exit = false, flg_EKF_inited;
bool   scan_pub_en = false, dense_pub_en = false, scan_body_pub_en = false;
double publish_limit_z = 1000000.0;
int publish_dense_skip = 1;
int publish_downsample_points = 1000000;
int publish_path_skip = 1;
bool adaptive_voxelization = false;
std::vector<double> adaptive_threshold;
std::vector<double> adaptive_multiple_factor;
bool init_gravity_with_pose;

vector<vector<int>>  pointSearchInd_surf;
vector<PointVector>  Nearest_Points;
vector<double>       extrinT(3, 0.0);
vector<double>       extrinR(9, 0.0);
vector<double>       extrinT_encoder(3, 0.0);
vector<double>       extrinR_encoder(9, 0.0);
deque<double>                     time_buffer;
deque<PointCloudXYZI::Ptr>        lidar_buffer;
deque<sensor_msgs::Imu::ConstPtr> imu_buffer;
deque<nav_msgs::Odometry::ConstPtr> encoder_buffer;

PointCloudXYZI::Ptr featsFromMap(new PointCloudXYZI());
PointCloudXYZI::Ptr feats_undistort(new PointCloudXYZI());
PointCloudXYZI::Ptr feats_down_body(new PointCloudXYZI());
PointCloudXYZI::Ptr feats_down_world(new PointCloudXYZI());
PointCloudXYZI::Ptr normvec(new PointCloudXYZI(100000, 1));
//PointCloudXYZI::Ptr laserCloudOri(new PointCloudXYZI(100000, 1));
//PointCloudXYZI::Ptr corr_normvect(new PointCloudXYZI(100000, 1));
PointCloudXYZI::Ptr _featsArray;
std::vector<M3D> var_down_body;

pcl::VoxelGrid<PointType> downSizeFilterSurf;
pcl::VoxelGrid<PointType> downSizeFilterAdaptive;
pcl::RandomSample<PointType> downSizeFilterVis;

std::vector<float> nn_dist_in_feats;
std::vector<float> nn_plane_std;
PointCloudXYZI::Ptr feats_with_correspondence(new PointCloudXYZI());

V3F XAxisPoint_body(LIDAR_SP_LEN, 0.0, 0.0);
V3F XAxisPoint_world(LIDAR_SP_LEN, 0.0, 0.0);
V3D euler_cur;
V3D position_last(Zero3d);
V3D Lidar_T_wrt_IMU(Zero3d);
M3D Lidar_R_wrt_IMU(Eye3d);

SO3 R_lidar_o_encoder(Eye3d);
V3D t_lidar_o_encoder(Zero3d);
SO3 R_encoder_o_zero_point(Eye3d);

// params for voxel mapping algorithm
double min_eigen_value = 0.003;
int max_layer = 0;

int max_cov_points_size = 50;
int max_points_size = 50;
double sigma_num = 2.0;
double max_voxel_size = 1.0;
std::vector<int> layer_size;

double ranging_cov = 0.0;
double angle_cov = 0.0;
std::vector<double> layer_point_size;

bool publish_voxel_map = false;
int publish_max_voxel_layer = 0;

std::unordered_map<VOXEL_LOC, OctoTree *> voxel_map;

/*** EKF inputs and output ***/
MeasureGroup Measures;
esekfom::esekf<state_ikfom, 12, input_ikfom> kf;
state_ikfom state_point, state_point_prev;
vect3 pos_lid;

nav_msgs::Path path;
nav_msgs::Odometry odomAftMapped;
geometry_msgs::Quaternion geoQuat;
geometry_msgs::PoseStamped msg_body_pose;

shared_ptr<Preprocess> p_pre(new Preprocess());
shared_ptr<ImuProcess> p_imu(new ImuProcess());

void SigHandle(int sig)
{
    flg_exit = true;
    ROS_WARN("catch sig %d", sig);
    sig_buffer.notify_all();
}

const bool var_contrast(pointWithCov &x, pointWithCov &y) {
    return (x.cov.diagonal().norm() < y.cov.diagonal().norm());
};

void pointBodyToWorld_ikfom(PointType const * const pi, PointType * const po, state_ikfom &s)
{
    V3D p_body(pi->x, pi->y, pi->z);
    V3D p_global(s.rot * (s.offset_R_L_I*p_body + s.offset_T_L_I) + s.pos);

    po->x = p_global(0);
    po->y = p_global(1);
    po->z = p_global(2);
    po->intensity = pi->intensity;
}


void pointBodyToWorld(PointType const * const pi, PointType * const po)
{
    V3D p_body(pi->x, pi->y, pi->z);
    V3D p_global(state_point.rot * (state_point.offset_R_L_I*p_body + state_point.offset_T_L_I) + state_point.pos);

    po->x = p_global(0);
    po->y = p_global(1);
    po->z = p_global(2);
//    po->intensity = pi->intensity;
}

template<typename T>
void pointBodyToWorld(const Matrix<T, 3, 1> &pi, Matrix<T, 3, 1> &po)
{
    V3D p_body(pi[0], pi[1], pi[2]);
    V3D p_global(state_point.rot * (state_point.offset_R_L_I*p_body + state_point.offset_T_L_I) + state_point.pos);

    po[0] = p_global(0);
    po[1] = p_global(1);
    po[2] = p_global(2);
}

void RGBpointBodyToWorld(PointType const * const pi, PointType * const po)
{
    V3D p_body(pi->x, pi->y, pi->z);
    V3D p_global(state_point.rot * (state_point.offset_R_L_I*p_body + state_point.offset_T_L_I) + state_point.pos);

    po->x = p_global(0);
    po->y = p_global(1);
    po->z = p_global(2);
    po->intensity = pi->intensity;
}

void RGBpointBodyLidarToIMU(PointType const * const pi, PointType * const po)
{
    V3D p_body_lidar(pi->x, pi->y, pi->z);
    V3D p_body_imu(state_point.offset_R_L_I*p_body_lidar + state_point.offset_T_L_I);

    po->x = p_body_imu(0);
    po->y = p_body_imu(1);
    po->z = p_body_imu(2);
    po->intensity = pi->intensity;

    po->curvature = pi->curvature;
    po->normal_x = pi->normal_x;
}

void standard_pcl_cbk(const sensor_msgs::PointCloud2::ConstPtr &msg)
{
    auto time_offset = lidar_time_offset;
//    std::printf("lidar offset:%f\n", lidar_time_offset);
    mtx_buffer.lock();
    scan_count ++;
    double preprocess_start_time = omp_get_wtime();
    if (msg->header.stamp.toSec() + time_offset < last_timestamp_lidar)
    {
//        ROS_ERROR("lidar loop back, clear buffer");
        ROS_ERROR("lidar loop back, skip this scan!!!");
//        lidar_buffer.clear();
        mtx_buffer.unlock();
        sig_buffer.notify_all();
        return;
    }

    PointCloudXYZI::Ptr  ptr(new PointCloudXYZI());
    p_pre->process(msg, ptr);
    // 删除过少的点
    // std::printf("points: %ld\n", ptr->size());
    if (ptr->size() < 120)
    {
//        ROS_ERROR("lidar loop back, clear buffer");
        ROS_ERROR("Too few points, skip this scan!!!");
//        lidar_buffer.clear();
        mtx_buffer.unlock();
        sig_buffer.notify_all();
        return;
    }

    lidar_buffer.push_back(ptr);
    time_buffer.push_back(msg->header.stamp.toSec() + time_offset);
    last_timestamp_lidar = msg->header.stamp.toSec() + time_offset;
    s_plot11[scan_count] = omp_get_wtime() - preprocess_start_time;
    mtx_buffer.unlock();
    sig_buffer.notify_all();
}

double timediff_lidar_wrt_imu = 0.0;
bool   timediff_set_flg = false;
void livox_pcl_cbk(const livox_ros_driver::CustomMsg::ConstPtr &msg)
{
    mtx_buffer.lock();
    double preprocess_start_time = omp_get_wtime();
    scan_count ++;
    if (msg->header.stamp.toSec() < last_timestamp_lidar)
    {
//        ROS_ERROR("lidar loop back, clear buffer");
        ROS_ERROR("lidar loop back, skip this scan!!!");
//        lidar_buffer.clear();
        mtx_buffer.unlock();
        sig_buffer.notify_all();
        return;
    }
    last_timestamp_lidar = msg->header.stamp.toSec();

    if (!time_sync_en && abs(last_timestamp_imu - last_timestamp_lidar) > 10.0 && !imu_buffer.empty() && !lidar_buffer.empty() )
    {
        printf("IMU and LiDAR not Synced, IMU time: %lf, lidar header time: %lf \n",last_timestamp_imu, last_timestamp_lidar);
    }

    if (time_sync_en && !timediff_set_flg && abs(last_timestamp_lidar - last_timestamp_imu) > 1 && !imu_buffer.empty())
    {
        timediff_set_flg = true;
        timediff_lidar_wrt_imu = last_timestamp_lidar + 0.1 - last_timestamp_imu;
        printf("Self sync IMU and LiDAR, time diff is %.10lf \n", timediff_lidar_wrt_imu);
    }

    PointCloudXYZI::Ptr  ptr(new PointCloudXYZI());
    p_pre->process(msg, ptr);
    lidar_buffer.push_back(ptr);
    time_buffer.push_back(last_timestamp_lidar);

    s_plot11[scan_count] = omp_get_wtime() - preprocess_start_time;
    mtx_buffer.unlock();
    sig_buffer.notify_all();
}

void imu_cbk(const sensor_msgs::Imu::ConstPtr &msg_in)
{
    publish_count ++;
    // cout<<"IMU got at: "<<msg_in->header.stamp.toSec()<<endl;
    sensor_msgs::Imu::Ptr msg(new sensor_msgs::Imu(*msg_in));

    if (abs(timediff_lidar_wrt_imu) > 0.1 && time_sync_en)
    {
        msg->header.stamp = \
        ros::Time().fromSec(timediff_lidar_wrt_imu + msg_in->header.stamp.toSec());
    }

    double timestamp = msg->header.stamp.toSec();

    if (timestamp < last_timestamp_imu)
    {
//        ROS_WARN("imu loop back, clear buffer");
//        imu_buffer.clear();
        ROS_WARN("imu loop back, ignoring!!!");
        ROS_WARN("current T: %f, last T: %f", timestamp, last_timestamp_imu);
        return;
    }
    // 剔除异常数据
    if (std::abs(msg->angular_velocity.x) > 10
        || std::abs(msg->angular_velocity.y) > 10
        || std::abs(msg->angular_velocity.z) > 10) {
        ROS_WARN("Large IMU measurement!!! Drop Data!!! %.3f  %.3f  %.3f",
                 msg->angular_velocity.x,
                 msg->angular_velocity.y,
                 msg->angular_velocity.z
        );
        return;
    }

//    // 如果是第一帧 拿过来做重力对齐
//    // TODO 用多帧平均的重力
//    if (is_first_imu) {
//        double acc_vec[3] = {msg_in->linear_acceleration.x, msg_in->linear_acceleration.y, msg_in->linear_acceleration.z};
//
//        R__world__o__initial = SO3(g2R(Eigen::Vector3d(acc_vec)));
//
//        is_first_imu = false;
//    }

    last_timestamp_imu = timestamp;

    mtx_buffer.lock();

    imu_buffer.push_back(msg);
    mtx_buffer.unlock();
    sig_buffer.notify_all();
}

void encoder_cbk(const nav_msgs::Odometry::ConstPtr &msg_in)
{
    encoder_buffer.push_back(msg_in);
}

double lidar_mean_scantime = 0.0;
int    scan_num = 0;
bool sync_packages(MeasureGroup &meas)
{
    if (lidar_buffer.empty() || imu_buffer.empty()) {
        return false;
    }

    /*** push a lidar scan ***/
    if(!lidar_pushed)
    {
        meas.lidar = lidar_buffer.front();
        meas.lidar_beg_time = time_buffer.front();
        if (meas.lidar->points.size() <= 1) // time too little
        {
            lidar_end_time = meas.lidar_beg_time + lidar_mean_scantime;
            ROS_WARN("Too few input point cloud!\n");
        }
        else if (meas.lidar->points.back().curvature / double(1000) < 0.5 * lidar_mean_scantime)
        {
            lidar_end_time = meas.lidar_beg_time + lidar_mean_scantime;
        }
        else
        {
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
int main(int argc, char** argv)
{
    ros::init(argc, argv, "laserMapping");
    ros::NodeHandle nh;

    nh.param<double>("time_offset", lidar_time_offset, 0.0);

    nh.param<bool>("publish/path_en",path_en, true);
    nh.param<bool>("publish/scan_publish_en",scan_pub_en, true);
    nh.param<bool>("publish/dense_publish_en",dense_pub_en, true);
    nh.param<bool>("publish/scan_bodyframe_pub_en",scan_body_pub_en, true);
    nh.param<double>("publish/intensity_th", intensity_th, 1.0);

    nh.param<string>("common/lid_topic",lid_topic,"/livox/lidar");
    nh.param<string>("common/imu_topic", imu_topic,"/livox/imu");
    nh.param<string>("common/encoder_topic", encoder_topic,"/encoder");
    nh.param<bool>("common/time_sync_en", time_sync_en, false);

    // mapping algorithm params
    nh.param<float>("mapping/det_range",DET_RANGE,300.f);
    nh.param<int>("mapping/max_iteration", NUM_MAX_ITERATIONS, 4);
    nh.param<int>("mapping/max_points_size", max_points_size, 100);
    nh.param<int>("mapping/max_cov_points_size", max_cov_points_size, 100);
    nh.param<vector<double>>("mapping/layer_point_size", layer_point_size,vector<double>());
    nh.param<int>("mapping/max_layer", max_layer, 2);
    nh.param<double>("mapping/voxel_size", max_voxel_size, 1.0);
    nh.param<double>("mapping/down_sample_size", filter_size_surf_min, 0.5);
    std::cout << "filter_size_surf_min:" << filter_size_surf_min << std::endl;
    nh.param<double>("mapping/plannar_threshold", min_eigen_value, 0.01);
    nh.param<bool>("mapping/extrinsic_est_en", extrinsic_est_en, true);
    nh.param<vector<double>>("mapping/extrinsic_T", extrinT, vector<double>());
    nh.param<vector<double>>("mapping/extrinsic_R", extrinR, vector<double>());
    nh.param<bool>("mapping/encoder_fusion_en", encoder_fusion_en, false);
    nh.param<vector<double>>("mapping/extrinsic_T_encoder_lidar", extrinT_encoder, vector<double>());
    nh.param<vector<double>>("mapping/extrinsic_R_encoder_lidar", extrinR_encoder, vector<double>());
    nh.param<double>("mapping/encoder_offset_deg", encoder_zeropoint_offset_deg, 0);
    nh.param<bool>("mapping/adaptive_voxelization", adaptive_voxelization, false);
    nh.param<vector<double>>("mapping/adaptive_threshold", adaptive_threshold, vector<double>({1000}));
    nh.param<vector<double>>("mapping/adaptive_multiple_factor", adaptive_multiple_factor, vector<double>({2.0}));
    nh.param<bool>("mapping/init_gravity_with_pose", init_gravity_with_pose, false);

    // noise model params
    nh.param<double>("noise_model/ranging_cov", ranging_cov, 0.02);
    nh.param<double>("noise_model/angle_cov", angle_cov, 0.05);
    nh.param<double>("noise_model/gyr_cov",gyr_cov,0.1);
    nh.param<double>("noise_model/acc_cov",acc_cov,0.1);
    nh.param<double>("noise_model/b_gyr_cov",b_gyr_cov,0.0001);
    nh.param<double>("noise_model/b_acc_cov",b_acc_cov,0.0001);

    // visualization params
    nh.param<bool>("publish/pub_voxel_map", publish_voxel_map, false);
    nh.param<int>("publish/publish_max_voxel_layer", publish_max_voxel_layer, 0);
    nh.param<int>("publish/publish_downsample_points", publish_downsample_points, 1000000);
    nh.param<int>("publish/publish_dense_skip", publish_dense_skip, 1);
    nh.param<int>("publish/publish_path_skip", publish_path_skip, 1);
    nh.param<double>("publish/publish_limit_z", publish_limit_z, 1000000.0);

    nh.param<double>("preprocess/blind", p_pre->blind, 0.01);
    nh.param<int>("preprocess/lidar_type", p_pre->lidar_type, AVIA);
    nh.param<int>("preprocess/scan_line", p_pre->N_SCANS, 16);
    nh.param<int>("preprocess/scan_rate", p_pre->SCAN_RATE, 10);
    nh.param<int>("preprocess/point_filter_num", p_pre->point_filter_num, 1);
    nh.param<bool>("preprocess/feature_extract_enable", p_pre->feature_enabled, false);
    cout<<"p_pre->lidar_type "<<p_pre->lidar_type<<endl;
    for (int i = 0; i < layer_point_size.size(); i++) {
        layer_size.push_back(layer_point_size[i]);
    }

    path.header.stamp    = ros::Time::now();
    path.header.frame_id ="camera_init";

    /*** variables definition ***/
    int effect_feat_num = 0, frame_num = 0;
    bool flg_EKF_converged, EKF_stop_flg = 0;
    scan_index = 0;

    _featsArray.reset(new PointCloudXYZI());

    memset(point_selected_surf, true, sizeof(point_selected_surf));
    memset(res_last, -1000.0f, sizeof(res_last));
    downSizeFilterSurf.setLeafSize(filter_size_surf_min, filter_size_surf_min, filter_size_surf_min);
    memset(point_selected_surf, true, sizeof(point_selected_surf));
    memset(res_last, -1000.0f, sizeof(res_last));

    Lidar_T_wrt_IMU<<VEC_FROM_ARRAY(extrinT);
    Lidar_R_wrt_IMU<<MAT_FROM_ARRAY(extrinR);
    p_imu->set_extrinsic(Lidar_T_wrt_IMU, Lidar_R_wrt_IMU);
    p_imu->set_gyr_cov(V3D(gyr_cov, gyr_cov, gyr_cov));
    p_imu->set_acc_cov(V3D(acc_cov, acc_cov, acc_cov));
    p_imu->set_gyr_bias_cov(V3D(b_gyr_cov, b_gyr_cov, b_gyr_cov));
    p_imu->set_acc_bias_cov(V3D(b_acc_cov, b_acc_cov, b_acc_cov));
    p_imu->set_init_gravity_with_pose(init_gravity_with_pose);

    // calc encoder w.r.t lidar extrinsic
    M3D MAT_R_encoder_o_lidar;
    V3D t_encoder_o_lidar;
    t_encoder_o_lidar<<VEC_FROM_ARRAY(extrinT_encoder);
    MAT_R_encoder_o_lidar<<MAT_FROM_ARRAY(extrinR_encoder);
    SO3 R_encoder_o_lidar = MAT_R_encoder_o_lidar;
    // inverse for convenient
    R_lidar_o_encoder = R_encoder_o_lidar.inverse();
    t_lidar_o_encoder = -(R_lidar_o_encoder * t_encoder_o_lidar);
    // encoder zero-point offset
    R_encoder_o_zero_point = Eigen::AngleAxisd(
            encoder_zeropoint_offset_deg / 180.0 * M_PI, V3D::UnitZ());

    double epsi[23] = {0.001};
    fill(epsi, epsi+23, 0.001);
    kf.init_dyn_share(get_f, df_dx, df_dw, observation_model_share, NUM_MAX_ITERATIONS, epsi);

    /*** ROS subscribe initialization ***/
    sub_pcl = p_pre->lidar_type == AVIA ? \
        nh.subscribe(lid_topic, 200000, livox_pcl_cbk) : \
        nh.subscribe(lid_topic, 200000, standard_pcl_cbk);
    sub_imu = nh.subscribe(imu_topic, 200000, imu_cbk);
    sub_encoder = nh.subscribe(encoder_topic, 200000, encoder_cbk);
    pubLaserCloudFull = nh.advertise<sensor_msgs::PointCloud2>("/cloud_registered", 100000);
    pubLaserCloudFull_body = nh.advertise<sensor_msgs::PointCloud2>("/cloud_registered_body", 100000);
    pubLaserCloudEffect = nh.advertise<sensor_msgs::PointCloud2>("/cloud_effected", 100000);
    pubLaserCloudMap = nh.advertise<sensor_msgs::PointCloud2>("/Laser_map", 100000);
    pubOdomAftMapped = nh.advertise<nav_msgs::Odometry>("/Odometry", 100000);
    pubOdomEncoderBody = nh.advertise<nav_msgs::Odometry>("/Encoder", 100000);
    pubExtrinsic = nh.advertise<nav_msgs::Odometry>("/Extrinsic", 100000);
    pubPath = nh.advertise<nav_msgs::Path>("/path", 100000);
    voxel_map_pub = nh.advertise<visualization_msgs::MarkerArray>("/planes", 10000);
    stats_pub = nh.advertise<nav_msgs::Odometry>("/stats", 10000);

//------------------------------------------------------------------------------------------------------
    // statistic
    stat_latency.setf(ios::fixed);
    stat_latency.precision(10);//精度为输出小数点后5位
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

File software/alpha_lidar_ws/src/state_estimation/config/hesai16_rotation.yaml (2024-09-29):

common:
    lid_topic:  "/velodyne_points"
#    imu_topic:  "/imu/data"
    imu_topic:  "/imu/data"
    encoder_topic:  "/imu/encoder"
    time_sync_en: false         # ONLY turn on when external time synchronization is really not possible
    
preprocess:
    lidar_type: 2                # 1 for Livox serials LiDAR, 2 for Velodyne LiDAR, 3 for ouster LiDAR, 
    scan_line: 16
    scan_rate: 10                # only need to be set for velodyne, unit: Hz,
    blind: 1.0
    point_filter_num: 1

mapping:
    down_sample_size: 0.3
    max_iteration: 4
#    voxel_size: 1.0
#    max_layer: 3                # 4 layer, 0, 1, 2, 3
    voxel_size: 0.25
    max_layer: 2                # 4 layer, 0, 1, 2, 3
    layer_point_size: [ 5, 5, 5, 5, 5 ]
    plannar_threshold: 0.01
    # test normal rectification
#    max_points_size: 100000
#    max_cov_points_size: 100000
    max_points_size: 1000
    max_cov_points_size: 1000
    init_gravity_with_pose: true

    fov_degree:    360
    det_range:     100.0
    extrinsic_est_en:  false      # true: enable the online estimation of IMU-LiDAR extrinsic,
    extrinsic_T: [-0.025, 0, -0.06 ]
    extrinsic_R: [0, -1, 0,
                  -1, 0, 0,
                  0, 0, -1]

    encoder_fusion_en: true     # true: enable encoder angle fusion,
    extrinsic_T_encoder_lidar:  [0.00581, 0.01437, 0.10497]
    extrinsic_R_encoder_lidar: [3.63e-05, 0.0001935, 1.0,
                                0.999992, -0.004, -3.56e-05,
                                0.004, 0.999992, -0.0001937]
    encoder_offset_deg: -60
                

noise_model:
    ranging_cov: 0.02
    angle_cov: 0.1
    # v2的硬件 imu cov调低一点效果好
    #    acc_cov: 0.05
    #    gyr_cov: 0.0025
    acc_cov: 0.1
    gyr_cov: 0.01
    #    acc_cov: 1.0
    #    gyr_cov: 0.5
    b_acc_cov: 0.000043
    b_gyr_cov: 0.00000266

publish:
    pub_voxel_map: false
    publish_max_voxel_layer: 10         # only publish 0,1,2 layer's plane
    path_en:  true
    scan_publish_en:  true       # false: close all the point cloud output
    dense_publish_en: true       # false: low down the points number in a global-frame point clouds scan.
    scan_bodyframe_pub_en: true  # true: output the point cloud scans in IMU-body-frame
    intensity_th: 0
    publish_limit_z: 150
    publish_dense_skip: 2

pcd_save:
    pcd_save_en: false
    interval: -1                 # how many LiDAR frames saved in each pcd file; 
                                 # -1 : all frames will be saved in ONE pcd file, may lead to memory crash when having too much frames.

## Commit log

2024-09-18 Add first version of hardware design
    [body.step, center_adapter.step, stand.step]
2024-09-19 Hardware-related documentation updated.
    [EasyEDA_PCB_host_machine_interface.json, center_mounting_structure.step, motor_mounting_base.step]
2024-09-29 update CAD files
    [center_mounting_structure_hesai.step, center_mounting_structure_ra16.step]
2024-09-29 update wiring guide
2024-10-10 update pc assembly diagram
